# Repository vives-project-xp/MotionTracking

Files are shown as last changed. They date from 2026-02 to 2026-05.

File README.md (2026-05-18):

# Motion Tracking


> Een podium-tracking systeem die licht/visuals aanstuurt door middel van bewegingen van de artiest op het podium

## Opdracht

Het doel van dit project is het ontwikkelen van een **Podium-Tracking** systeem. Dit systeem is bedoeld om bewegingen van artiesten op te detecteren en deze accuraat te volgen. De data die hieruit voortvloeit wordt gebruikt om Licht/Visuals dynamisch te laten veranderen

## Inhoud

### Software

De broncode voor de tracking algoritmes en aansturing is te vinden in de [Software](Software/README.md) map. We maken gebruik van Python, OpenCV, YOLO,... voor de beeldverwerking en data-analyse.

### Documentatie

De algemene documentatie voor het project is te vinden in de [Documentatie](Documentatie/README.md) map. Hierin vind je technische specificaties, flowcharts en uitleg over de werking van het tracking algoritme.

### Research

Alle onderzoeken voor het project kan men terug vinden in de [Research](Research/README.md) map. Hierin vind je gevonden informatie, ruwe datasheets,...

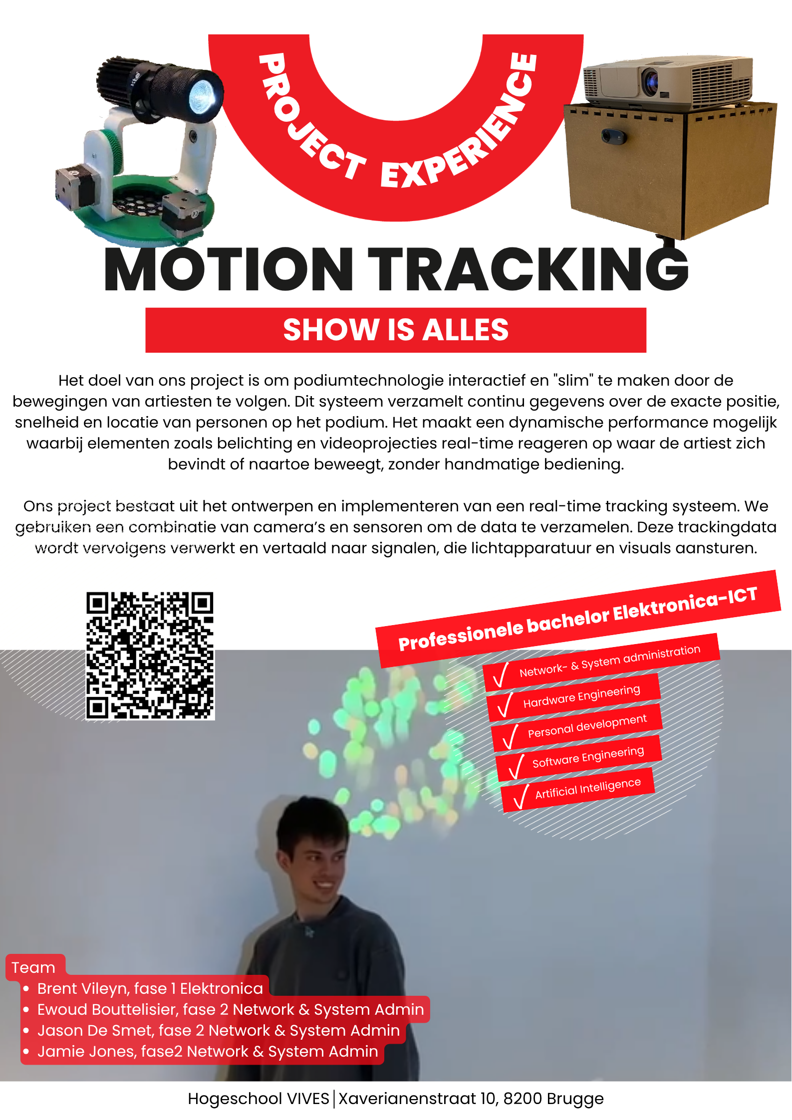
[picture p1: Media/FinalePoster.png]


### Installatie Motion Tracking met projector
#### Benodigdheden:
- Projector of groot scherm
- Raspberry Pi 5 + hailo ai kit
- USB Camera -> verbonden met raspberry
- Radxa Rock 5B of sterker apparaat   -> verbonden met projector
- Virtuele Machine op server of iets waar je website op kan hosten

#### Stappen:

1. **Clone** de github-repo op de Raspberry Pi 5, Rock en VM.

2. Lokaliseer de juiste **files** per **apparaat**: map Visual_output > Radxa Rock | map Hailo_tracking > Raspberry Pi 5 Hailo Kit | map Vm > Virtuele Machine op server

3. Sluit de **camera** aan op de Raspberry Pi 5 en de projector op de Radxa Rock

4. Zorg ervoor dat de Projector en camera steeds **goed gepositioneerd** blijven (dit kan met een statief + plaat).

5. Start het script **hailo_apps/hailo_app_python/start_tracking** op de Raspberry Pi en ook het script **visual_output/main.py** starten op de Rock.

6. Laat de camera de **fudicials** tracken, als de fudicials dan verdwijnen zou de **tracking** moeten **opgestart** zijn.

7. Surf naar het **IP-adres** van uw **VM** op poort 80:

```bash
[IP-Adres]:80
```

### Gebruik
1. **Start** alles **op** (zie installatie).

2. Ga **voor** de **camera** staan/bewegen om **effecten** te zien op de projector.

3. Pas **achtergronden** en **effecten** aan op de website om mooie **visuals** te krijgen.

### Installatie Motion Tracking met Moving Spot
#### Benodigdheden:
- 2X ESP32-C3-DevKitC-02
- Radar Sensor (mmWave-sensor) (Ai-Thinker Rd-03D 24GHz Radar Sensor Module)
- Arduino Uno
- QShield Servo Driver Board
- Servo Motoren (Nema 17)
- Spotlight Lamp (Eurolite LED PST-12W 6000K Spot)

#### Stappen voor installatie van Radar

 1. Lokaliseer de juiste **files** door te Navigeren naar : Software > Radar > Radar_code > Radar_code.ino .
 2. Verbind de Esp en de Radar met elkaar via een usb-a kabel.
 3. Upload de Radar_code.ino naar de esp.
 4. Hang de radar op de positie waar de personen wilt tracken.
 5. Verbind de radar via deze wijze :
    | Radar | ESP32          |
    |-------|----------------|
    | RX    | TX (Pin 18)    |
    | TX    | RX (Pin 19)    |
    | 5V    | 5V             |
    | GND   | GND            |

 #### Stappen voor MQTT Receiver Esp

 1. Lokaliseer de juiste **files** door te navigeren naar : Software > Radar > tweed_esp > mqtt_sender > mqtt_sender.ino 
 2. Connecteer je esp met je computer en upload de mqtt_sender.ino code naar je esp.
 3. Connecteer je esp met de arduino :

    | Pinout ESP | Pinout Arduino |
    |------------|----------------|
    | GND        | GND            |
    | TX (pin 21)| Pin 2          |
    | RX (pin 5) **optioneel**| Pin 3 **optioneel**|

## Team

| Team | Afstudeerrichting |
| --- | --- |
| [ Brent Vileyn](https://github.com/Brent69420809) | Elektronica |
| [ EwoudBoutje](https://github.com/EwoudBoutje) |  Network & System Admin  |
| [ Jason De Smet](https://github.com/JasonDeSmet2025) | Network & System Admin |
| [ Jamie Jones](https://github.com/JollyJones101) | Network & System Admin |

## Planning

### Sprint 1 (Week 1-4):
- [ ]  Alle componenten besteld
- [ ] Camera doen werken op Raspberry Pi + Scherm herkennen met testcode
- [ ] Radar Module onderzoeken + schema's maken
- [ ] Visuals onderzoeken + hoe uit pi krijgen

### Sprint 2 (Week 5-8)
- [ ] Eerst prototype afgewerkt
- [ ] Foto's & video's voor sociale media
- [ ] Visual dynamisch kunnen aanpassen aan artiest

### Sprint 3 (Week 9-15)
- [ ] volledig werkende visuals show
- [ ] eventuele uitbreidingen toepassen
- [ ] documentatie afgewerkt

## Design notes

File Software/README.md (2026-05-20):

# Software
> Hier vindt men alle software

## Bestandsstructuur

```text
Software/
└── Archief
    └── Oude mappen/bestanden
└── Arduino
    └── Files voor Arduino
└── Hailo_tracking
    └── basic_pipelines
    └── hailo_apps
└── Radar/
    └── Radar_Code/
        └── Radar_Code.ino
└── Visual_output
    └── demo_radar: files om radar te tonen op projector
    └── Markers: fiducials om projector uit te lezen
    └── Media: Foto's en video's voor op projector
    └── files om programma uit te voeren voor op de rock       
└── Vm
    └── files voor de website

```
---
## VM - Web control panel

De map `Vm` bevat de webinterface waarmee de visuals op afstand worden ingesteld. Deze software draait op de virtuele machine/server en stuurt configuratie door via MQTT naar het toestel dat de projectie uitvoert.

### Inhoud van de map

| Bestand/map | Functie |
|---|---|
| `webcontrol.py` | Hoofdversie van het Flask webpaneel. Dit script draait op poort `80`, laadt de styling uit `static/style.css` en publiceert instellingen naar MQTT. |
| `oldweb.py` | Oude versie van het webpaneel, bewaard als backup. |
| `static/style.css` | CSS-bestand voor de opmaak van de webinterface. Flask serveert dit bestand automatisch via de `static` map. |
| `Media/` | Wordt automatisch aangemaakt. Hierin komen geuploade afbeeldingen en videos terecht. |

### Werking

De VM draait een Flask-server. Via de website kan men:

- een achtergrondkleur kiezen;
- een afbeelding of video uploaden als achtergrond;
- media hernoemen of verwijderen;
- een effectmodus kiezen, zoals `MAGIC`, `FIRE`, `CYBER`, `GHOST` of `COWBOY`;
- parameters aanpassen zoals `offset` en `spawn`;
- de trackingbron en doelpersoon instellen.

Bij elke wijziging stuurt `webcontrol.py` de volledige configuratie als JSON naar het MQTT-topic:

```text
vj/config
```

De MQTT broker staat standaard ingesteld op:

```python
MQTT_BROKER = "127.0.0.1"
```

Dit betekent dat de MQTT broker op dezelfde VM moet draaien als het webpaneel.

De HTML van het controlepaneel staat nog in `webcontrol.py`, maar de visuele opmaak staat apart in `static/style.css`. Hierdoor kan de layout aangepast worden zonder de Flask-routes of MQTT-logica te wijzigen.

### Installatie op de VM

Installeer Python en de nodige packages:

```bash
pip install flask werkzeug paho-mqtt
```

Zorg ook dat er een MQTT broker draait, bijvoorbeeld Mosquitto:

```bash
sudo apt install mosquitto mosquitto-clients
sudo systemctl enable mosquitto
sudo systemctl start mosquitto
```

### Starten

Navigeer naar de map:

```bash
cd Software/Vm
```

Start daarna het webpaneel:

```bash
python3 webcontrol.py
```

De website is bereikbaar via:

```text
http://<VM-IP>:80
```

Let op: poort `80` vereist op Linux vaak administratorrechten. Gebruik in dat geval:

```bash
sudo python3 webcontrol.py
```

### Belangrijke endpoints

| Endpoint | Functie |
|---|---|
| `/` | Hoofdpagina van het controlepaneel. |
| `/update` | Past instellingen aan en publiceert deze via MQTT. |
| `/upload` | Uploadt afbeeldingen of videos naar de VM. |
| `/rename` | Hernoemt een mediabestand. |
| `/delete` | Verwijdert een mediabestand. |
| `/media/<filename>` | Maakt media beschikbaar voor de visual-output client. |
| `/get_config` | Geeft de huidige configuratie terug als JSON. |

---
## Visual_output - Projectie en effecten

De map `Visual_output` bevat de software die op het projectietoestel draait, bijvoorbeeld een Radxa Rock 5B. Deze software opent een fullscreen Pygame-venster op de projector en tekent effecten op basis van trackingdata en instellingen uit de VM.

### Inhoud van de map

| Bestand/map | Functie |
|---|---|
| `main.py` | Hoofdprogramma voor de live visual-output. |
| `effects_lib.py` | Bevat de effect-presets, particle-logica, aura-effecten en background manager. |
| `requirements.txt` | Python dependencies voor de visual-output software. |
| `Media/` | Lokale cache voor afbeeldingen en videos die als achtergrond gebruikt worden. |
| `Markers/` | ArUco/fiducial markers voor projectorkalibratie. |
| `demo_radar/` | Demo-opstelling voor radarvisualisatie. |
| `Back_up*.py`, `old-main.py`, `main3.py`, `main_website.py` | Oudere of experimentele versies van de visual-output. |
| `yolov8n.pt` | YOLO modelbestand voor detectie/testopstellingen. |

### Werking

`main.py` luistert via MQTT naar twee topics:

| Topic | Inhoud |
|---|---|
| `vj/hailo` | Trackingdata van personen en markers. |
| `vj/config` | Instellingen vanuit het VM-webpaneel. |

De trackingdata bevat onder andere personen, lichaamsposities en markerposities. De configuratie bepaalt de achtergrond, kleurmodus, particle-spawn en offset.

De belangrijkste stappen in het programma zijn:

1. Verbinden met de MQTT broker op de VM.
2. Fullscreen Pygame-venster openen op de projector.
3. Kalibratiemarkers tonen zolang het scherm nog niet gekalibreerd is.
4. Een perspectieftransformatie berekenen zodra de markers herkend worden.
5. Trackingpunten omzetten naar projectorcoordinaten.
6. Achtergrond tekenen.
7. Effecten, aura's en particles tekenen rond handen en hoofd.

### Configuratie

In `main.py` moet het IP-adres van de VM juist staan:

```python
VM_IP = "10.20.10.18"
```

Pas dit aan naar het IP-adres van de VM waarop `webcontrol.py` en de MQTT broker draaien.

### Installatie

Navigeer naar de map:

```bash
cd Software/Visual_output
```

Maak eventueel een virtuele omgeving aan:

```bash
python3 -m venv .venv
source .venv/bin/activate
```

Installeer daarna de dependencies:

```bash
pip install -r requirements.txt
```

De gebruikte packages zijn onder andere:

- `pygame`
- `opencv-python`
- `numpy`
- `requests`
- `paho-mqtt`

### Starten

Start de visual-output:

```bash
python3 main.py
```

Het programma opent in fullscreen. Gebruik deze toetsen tijdens het draaien:

| Toets | Functie |
|---|---|
| `ESC` | Programma afsluiten. |
| `C` | Kalibratie opnieuw uitvoeren. |
| `S` | Kalibratie overslaan en het volledige scherm gebruiken. |

### Achtergronden en media

Wanneer via de VM een afbeelding of video gekozen wordt, controleert `BackgroundManager` of het bestand lokaal bestaat in `Visual_output/Media`. Als het bestand ontbreekt, wordt het automatisch gedownload vanaf:

```text
http://<VM-IP>/media/<filename>
```

Zo hoeft media enkel via het webpaneel op de VM geupload te worden. De visual-output haalt de bestanden zelf op wanneer ze nodig zijn.

### Kalibratie

Bij het opstarten toont `main.py` vier markers op de hoeken van het projectiebeeld. De camera/trackingsoftware moet deze markers detecteren en via `vj/hailo` doorsturen. Zodra alle vier markers gekend zijn, berekent de visual-output een perspectieftransformatie zodat de trackingpunten correct op de projectie verschijnen.

Als de markers niet gebruikt worden of als er snel getest moet worden, kan met `S` een standaardmapping over het volledige scherm gebruikt worden.

---
## Ai-Thinker RD-03D Radar Software

### Hoe de software werkt

#### 1. Data Ontvangst
De sensor stuurt pakketjes van **30 bytes** via UART op **256000 baud**. De software controleert eerst de volledige header én footer om te bevestigen dat het om een geldig datapakket gaat:

| Positie | Waarde | Beschrijving |
|---|---|---|
| Byte 0  | `0xAA` | Header byte 1 |
| Byte 1  | `0xFF` | Header byte 2 |
| Byte 2  | `0x03` | Header byte 3 |
| Byte 3  | `0x00` | Header byte 4 |
| Byte 4-5 | variabel | X-coördinaat (little-endian) |
| Byte 6-7 | variabel | Y-coördinaat (little-endian) |
| Byte 8-9 | variabel | Snelheid |
| Byte 10-11 | variabel | Afstandsresolutie |
| Byte 12-27 | `0x00` | Target 2 & 3 (niet gebruikt) |
| Byte 28 | `0x55` | Footer byte 1 |
| Byte 29 | `0xCC` | Footer byte 2 |

De software valideert elk frame door de header (`0xAA 0xFF 0x03 0x00`) en footer (`0x55 0xCC`) te controleren. Frames die hier niet aan voldoen worden weggegooid.

---

#### 2. Coördinaat Decodering
De ruwe X- en Y-waardes worden samengesteld via little-endian optelling:
**X-coördinaat (links/rechts):**
De sensor gebruikt een gedeeld bereik rond 32768 (2¹⁵):
- Rechterkant (positief): `x_raw < 32768` → `x_mm = x_raw`
- Linkerkant (negatief): `x_raw >= 32768` → `x_mm = -(x_raw - 32768)`

**Y-coördinaat (afstand voorwaarts):**
$$y_{mm} = y_{raw} - 32768$$

---

#### 3. Wiskundige Berekening
De software rekent de X- en Y-coördinaten om naar poolcoördinaten:

**Afstand** via de stelling van Pythagoras:
$$\text{afstand} = \frac{\sqrt{x_{mm}^2 + y_{mm}^2}}{10} \text{ cm}$$

**Hoek** via atan2:
$$\text{hoek} = \arctan2(x_{mm},\ y_{mm}) \times \frac{180}{\pi} \text{ graden}$$

Waarbij $0°$ recht vooruit is voor de radar, positieve graden rechts en negatieve graden links.

---

#### 4. Filters
Om ongeldige frames te verwijderen:
1. **Frame lengte**: Exact 30 bytes.
2. **Header & footer**: Moeten exact overeenkomen.
3. **Y-waarde**: Moet groter zijn dan 0 (target moet voor de sensor staan).

---

#### 5. MQTT Verzending
Na een geldige meting wordt de data via WiFi gepubliceerd op het MQTT topic `vj/radar` als CSV-string:

---

#### Gebruik in de Arduino IDE

1. Stel jouw **WiFi credentials** in bovenaan de code.
2. Stel het correcte **MQTT broker IP-adres** in (`mqtt_server`).
3. Upload de code naar de ESP32.
4. Open de **Serial Monitor** (`Ctrl` + `Shift` + `L`) op **115200 baud**.
5. De ESP32 verbindt automatisch met WiFi en de MQTT broker.
6. Je ziet nu serial output zoals: *X,Y,Distance,Angle*

### Bij de Arduino Uno
Om de data te ontvangen van de MQTT broker bij de Arduino Uno (die wordt gebruikt om de motoren aan te sturen) gebruiken we een tweede ESP32 omdat deze wel met Wifi kan verbinden.
We subcriben op de top vj/radar.
Zo sturen we dan alle data die we binnenkrijgen van de topic over de TX-pin die verbonden is met pin 2 op de Arduino.
De code voor deze ESP32 kan je vinden in *Radar/tweede_esp*.

### Documentatie Arduino
De documentaie over de arduino kan men [hier](/Documentatie/README.md) vinden.

---

**Richting referentie:**
- Beweeg je naar **links**? → Hoek gaat naar **negatieve** graden.
- Beweeg je naar **rechts**? → Hoek gaat naar **positieve** graden.
- Recht voor de sensor = **0°**.

---

### Gebruikte Libraries

| Library | Functie | Installatie |
|---|---|---|
| `WiFi.h` | WiFi verbinding | Ingebouwd in ESP32 core |
| `PubSubClient.h` | MQTT communicatie | Via Arduino Library Manager |
| `Arduino.h` | Arduino basis | Ingebouwd |

--- 
### Gebruikte Driver
[Driver](https://www.silabs.com/documents/public/software/CP210x_Universal_Windows_Driver.zip)

# Werking van de Hailo AI

Voor dit project hebben we de officiële **Hailo voorbeelden** (examples) van GitHub gehaald. Omdat die code standaard alleen bedoeld is om dingen op een scherm te laten zien, hebben we de code zelf aangepast. Hierdoor kunnen we nu specifiek de houding (pose estimation) van mensen uitlezen en deze data doorsturen.

---

## 🚀 Hoe werkt de Hailo software in dit project?

De code van GitHub zorgt ervoor dat de camera en de Hailo AI-chip (de NPU) met elkaar praten. Dit gebeurt via een zogenaamde video-pipeline. 

Wij hebben ingegrepen op het moment dat er een video-beeld binnenkomt. De Hailo-software doet dan achter de schermen het zware werk:

1. **Scannen naar mensen:** De AI scant het beeld en zoekt naar objecten met het label `"person"`.
2. **Kader maken (Bounding Box):** Als de AI een persoon vindt, trekt hij er een onzichtbaar kader omheen. De software onthoudt de coördinaten van dit kader (waar begint en stopt de persoon in het beeld).
3. **Skeletpunten zoeken (Landmarks):** Binnen dat kader gaat de AI op zoek naar het 'skelet' van de persoon. 

---

## 🛠️ Wat hebben wij aangepast voor de Pose Estimation?

De standaard code van GitHub gooit alle data op één grote hoop. Wij hebben de code zo aangepast dat we heel specifiek drie belangrijke punten uit het skelet filteren:
* De **neus**
* De **linkerhand**
* De **rechterhand**

### De berekening simpel uitgelegd
De Hailo geeft de locatie van de hand of neus door *binnen het kader van de persoon zelf*, en dus niet binnen het hele videoscherm. 

Wij hebben code toegevoegd die dit omrekent. Onze aanpassing zorgt ervoor dat de software kijkt naar de grootte van het kader, berekent waar de hand zich bevindt op het totale scherm, en dit omzet naar een simpel getal tussen `0.0` (helemaal links/boven) en `1.0` (helemaal rechts/onder).

Hierdoor hebben we een super nauwkeurige meting van waar de neus en handen zijn, die we direct kunnen doorsturen via MQTT!

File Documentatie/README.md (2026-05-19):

# Documentatie
> Hier vindt men alle documentatie

# Pan and Tilt Joint
Voor dit project hebben wij een pan and tilt joint gebruikt dat alle richtingen in kan draaien. Hiervoor bestaat al een mooi bestaand project: https://www.thingiverse.com/thing:4316563
We kunnen hier vinden hoe wij het samenstellen: https://www.youtube.com/watch?v=uJO7mv4-0PY
Voor het grote rollement hebben wij dit ook uitgeprint en gesmeerd zodat het vlot draait.
Beide stepper motors, namelijk de NEMA-17, zijn verbonden met een QShield v5d en het shield is verbonden aan de Arduino. Het QShield heeft minimaal 12V nodig. We voeden het met een adapter van 12V en 2A, wat voldoende is voor onze stepper motors. Daarna hebben wij deze lamp gemonteerd op het statief: https://www.bax-shop.be/nl/pinspot/eurolite-led-pst-12w-6000k-spot-smalle-beam-pinspot. Dit moet niet deze lamp zijn, maar is onze voorkeur.

# Code Pan and Tilt Joint
De code werd geschreven in C++ in de Arduino IDE voor de Arduino Uno die wij in dit project gebruiken. De broncode is hier te vinden: https://github.com/vives-project-xp/MotionTracking/tree/main/Software/Arduino

# Code Uitleg
De code bestuurt twee stepper motors via een niet-blokkerende scheduler:
Y-as (tilt): Bij het opstarten wordt de Y-as eerst gehomed. De motor beweegt richting de eindschakelaar (NC-bedrading), raakt deze aan, en rijdt dan een vaste afstand terug zodat de carriage vrij staat. Daarna wordt de positie op nul gezet. Tijdens normaal gebruik wordt de tilt-positie berekend op basis van de ontvangen afstandswaarde (0–500 cm), die lineair wordt omgezet naar een stappenpositie tussen Y_MIN_STEPS (600) en Y_MAX_STEPS (2200).
Z-as (pan): De motor volgt een doelhoek die rechtstreeks uit het datapakket wordt gehaald. De hoek wordt begrensd tussen −90° en +90°.
Beide assen werken met een interval-gebaseerde scheduler in loop(): elke as krijgt per iteratie slechts een klein aantal stappen toegewezen (Y_STEPS_PER_TICK, Z_STEPS_PER_TICK), zodat de seriële communicatie nooit geblokkeerd wordt.
Datapakket formaat: De ESP stuurt kommagescheiden pakketten via software-UART:
x,y,afstand,hoek
De code leest veld 2 (afstand) en veld 3 (hoek) uit elk pakket en past de doelposities van beide assen aan.
Veiligheid: Software-limieten voorkomen dat de motoren buiten hun fysieke bereik rijden. De eindschakelaar wordt ook tijdens normaal gebruik live uitgelezen en herstart de Y-as positie als deze onverwacht geactiveerd wordt.
# Radar Code Documentatie

## Overzicht
Deze code leest de data van een **Ai-Thinker RD-03D** mmWave radar sensor via UART, verwerkt de ruwe frames naar bruikbare coördinaten en stuurt deze via **MQTT over WiFi** door naar de rest van het systeem.

---

## Benodigde Libraries

| Library | Functie | Installatie |
|---|---|---|
| `WiFi.h` | WiFi verbinding | Ingebouwd in ESP32 core |
| `PubSubClient.h` | MQTT communicatie | Via Arduino Library Manager |
| `secrets.h` | WiFi & MQTT credentials | Zelf aanmaken (zie hieronder) |

---
## Gebruikte Artikels

[**Klik Hier**](https://www.electroniclinic.com/rd-03d-mmwave-radar-multi-human-tracking-with-distance-speed-positioning/)

---
## Gebruikte driver 
[**Driver**](https://www.silabs.com/documents/public/software/CP210x_Universal_Windows_Driver.zip)

## Configuratie

### secrets.h
Maak een bestand `secrets.h` aan in dezelfde map als de `.ino` file met de volgende inhoud:

```cpp
#ifndef SECRETS_H
#define SECRETS_H

#define SECRET_SSID "JOUW_WIFI_NAAM"
#define SECRET_PASS "JOUW_WIFI_PASWOORD"
#define SECRET_MQTT_SERVER "JOUW_IP_MQTT_SERVER"

#endif
```

### Pin configuratie
| Definitie | Pin | Beschrijving |
|---|-----|---|
| `RX_PIN` | 19 | UART ontvangst van radar TX |
| `TX_PIN` | 18 | UART verzending naar radar RX |
| `BAUD_RATE` | 256000 | UART snelheid |

---

## Hoe de code werkt

### 1. Opstarten (`setup`)
- Start de seriële monitor op 115200 baud voor debug output
- Start UART communicatie met de radar op 256000 baud
- Stuurt het `Single_Target_Detection_CMD` commando naar de radar om single-target modus te activeren
- Verbindt met WiFi via `setup_wifi()`
- Verbindt met de MQTT broker

### 2. Hoofdlus (`loop`)
- Controleert of de MQTT verbinding nog actief is, anders herverbindt via `reconnect()`
- Leest continu bytes binnen van de radar via UART
- Wanneer de footer bytes `0x55 0xCC` gedetecteerd worden, wordt `processRadarData()` aangeroepen

### 3. Frame validatie (`isValidFrame`)
Elk frame wordt gevalideerd op:
- Exacte lengte van 30 bytes
- Correcte header: `0xAA 0xFF 0x03 0x00`
- Correcte footer: `0x55 0xCC`

Ongeldige frames worden direct weggegooid.

### 4. Data verwerking (`processRadarData`)

**Ruwe bytes uitlezen:**
- x_raw = byte[4] + byte[5] * 256
- y_raw = byte[6] + byte[7] * 256

**X-coördinaat decodering:**
- x_raw < 32768  →  x_mm = x_raw          (rechterkant, positief)
- x_raw >= 32768 →  x_mm = -(x_raw - 32768)  (linkerkant, negatief)

**Y-coördinaat decodering:**
- y_mm = y_raw - 32768
- Frames waarbij `y_mm <= 0` worden geskipt (geen target voor de sensor).

**Berekeningen:**
$$\text{afstand} = \frac{\sqrt{x_{mm}^2 + y_{mm}^2}}{10} \text{ cm}$$

$$\text{hoek} = \arctan2(x_{mm},\ y_{mm}) \times \frac{180}{\pi} \text{ graden}$$
---

### 5. MQTT Verzending
De data wordt als CSV-string gepubliceerd op topic `vj/radar`:

x_mm,y_mm,afstand_cm,hoek_graden

Voorbeeld:

727,2034,214.7,19.7

---

## Richting referentie

| Positie | Hoek |
|---|---|
| Recht voor de sensor | 0° |
| Rechterkant | Positieve graden (+) |
| Linkerkant | Negatieve graden (-) |

---

## Serial Monitor output
Bij een geldige meting zie je:

Afstand: 214.7 cm  |  Hoek: 19.7 deg  |  Snelheid: 0 cm/s
MQTT verstuurd: 727,2034,214.7,19.7

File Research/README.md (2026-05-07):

# Research
> Hier vindt men alle research die we gedaan hebben

## Eventuele opstelling
- 1x Beamer om visuals te projecteren
- 1x Raspberry Pi 5 voor dherkenning en uitsturen van beeld
- Eigen gemaakte moving-head/spot (2x servomotoren, Spotlamp, drivers, ESP32(of andere)) die de artiest zal volgen
- 1x radar sensor om de artiest precieser te kunnen volgen

# Research - Radar Sensor

## Doel van het project
Het doel van het project is om één of meerdere artiesten te volgen met een licht.

---

## Sensorkeuze

### Waarom de RD-03D?
We hebben direct gekozen voor de Ai-Thinker RD-03D mmWave radar. Deze sensor had twee grote voordelen die voor ons project belangrijk waren:

- **Nauwkeurige tracking**: De sensor volgt een persoon heel precies.
- **Onderscheid tussen mens en object**: De sensor heeft een ingebouwd library dat het verschil kan zien tussen een mens en een gewoon object.

Een nadeel is dat de sensor heel gevoelig is. Hij pikt dus snel bewegingen op, wat goed is voor tracking maar ook betekent dat er veel ruismetingen kunnen binnenkomen.

---

## Bronnen

De belangrijkste bronnen die we gebruikt hebben:

- **Officiële datasheet** van Ai-Thinker: hierin vonden we het frame formaat, de standaard baudrate (256000 bps) en de elektrische specificaties deze kan je vinden onder de map Research > Datasheets > Ai-Thinker Rd-03D 24GHz Radar Sensor Module_Datasheet.pdf
- **Artikel van Electronic Clinic**: [Real-time Human Tracking Radar with mmWave Sensor and ESP32-S3 Touchscreen](https://www.electroniclinic.com/real-time-human-tracking-radar-with-mmwave-sensor-and-esp32-s3-touchscreen/)

Via het artikel hebben we een code gevonden die frames van de sensor stuurt, hoe de berekeningen voor de hoek werken en hoe we de correcte `x_mm` en `y_mm` waarden konden berekenen uit de ruwe bytes.

---

## Bevindingen

### Wat werkte goed
De tracking zelf werkt heel goed. De sensor detecteert een persoon snel als hij beweegt en volgt die vloeiend. De nauwkeurigheid is voldoende voor gebruik op een podium.

### Problemen
Het grootste probleem dat we tegenkwamen was dat veel van de binnengekomen frames incorrect waren. De sensor stuurt namelijk ook frames zonder nuttige data. Hiervoor hebben we een filter geschreven die elk frame valideert door de header (`0xAA 0xFF 0x03 0x00`) en footer (`0x55 0xCC`) te controleren, en frames met een ongeldige Y-waarde te negeren.

De decoding van de X-coördinaat was ook niet meteen duidelijk. Via trial and error met de ruwe data hebben we uiteindelijk de correcte formule gevonden:
- **Rechterkant** (positief): `x_mm = x_raw` wanneer `x_raw < 32768`
- **Linkerkant** (negatief): `x_mm = -(x_raw - 32768)` wanneer `x_raw >= 32768`

---

## Technische keuzes

| Keuze | Reden |
|---|---|
| **ESP32** | Heeft ingebouwde WiFi, nodig voor communicatie |
| **WiFi** | Meest praktisch voor draadloze communicatie op een podium |
| **MQTT** | Makkelijk protocol zodat alle componenten van het project met elkaar kunnen communiceren |

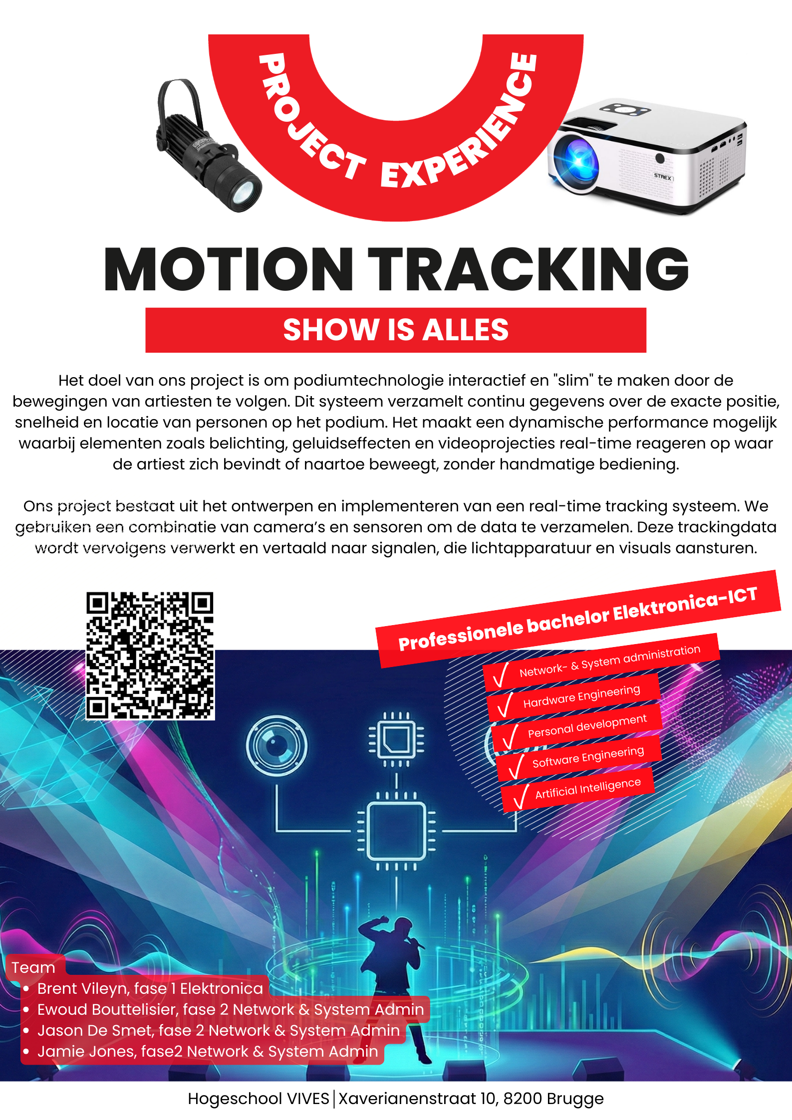
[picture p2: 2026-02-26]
Media/IntroductieposterPX9.png

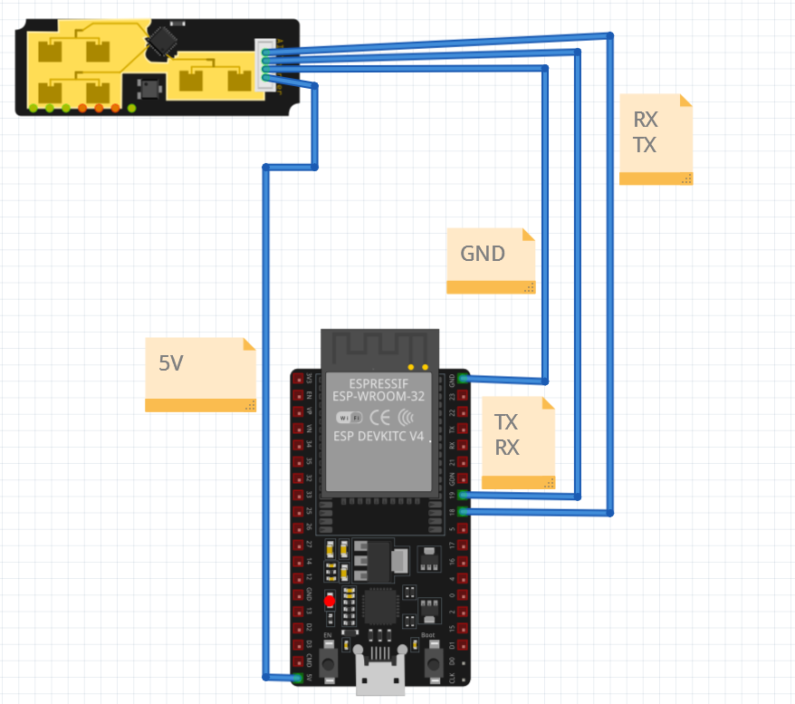
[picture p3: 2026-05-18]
Documentatie/schematics/Radar_schematic.png

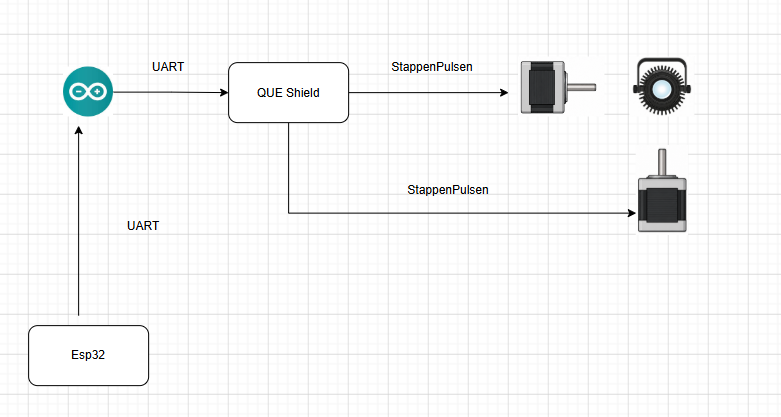
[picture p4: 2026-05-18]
Documentatie/schematics/Follow_Lamp_schematic.png

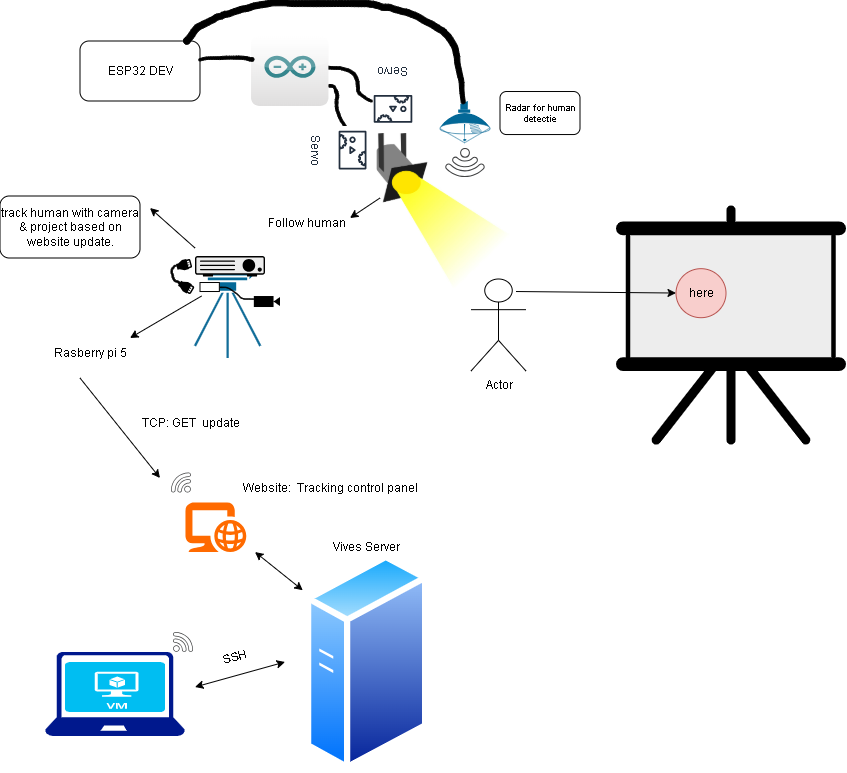
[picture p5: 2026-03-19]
Documentatie/schematics/Schematic.drawio.png

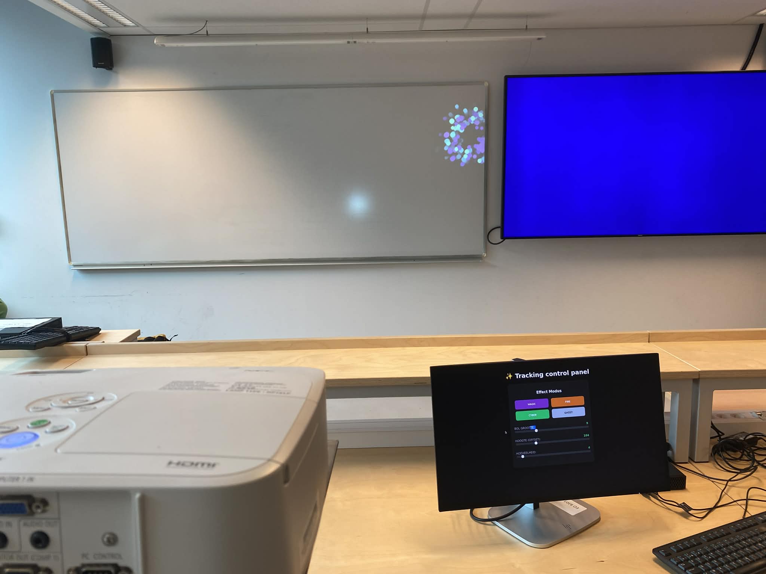
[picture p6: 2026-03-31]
Media/image_visuals.jpg

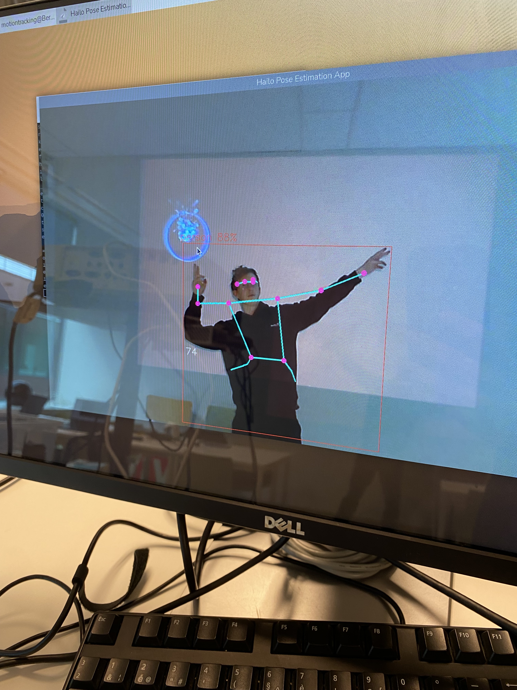
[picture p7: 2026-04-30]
Software/Visual_output/Media/Jamie.jpeg

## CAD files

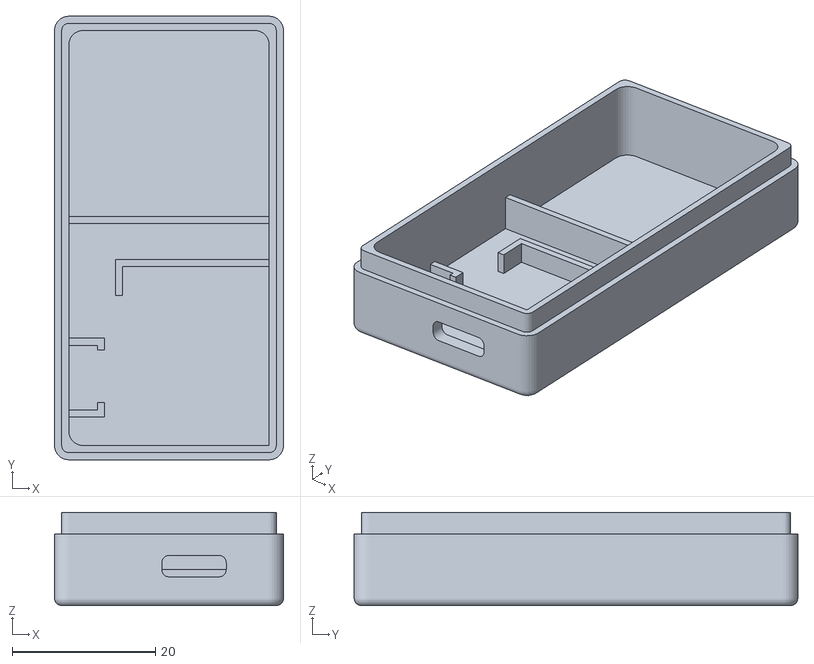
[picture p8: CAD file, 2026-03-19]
Archief/3Dfiles/Omhulsels/bottom_body_v2_ziSKXtXT1l.stl
32.0 x 62.0 x 13.0

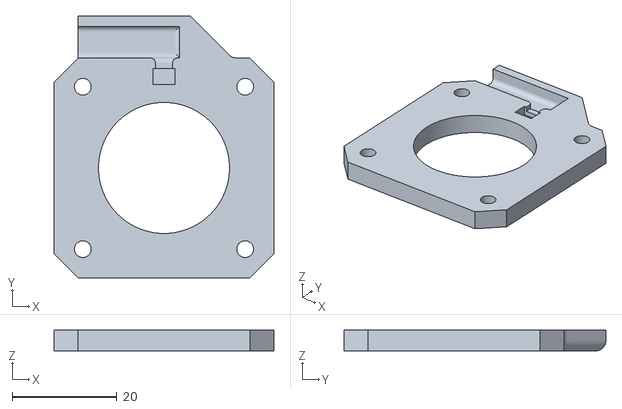
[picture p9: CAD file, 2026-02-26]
Archief/3Dfiles/Printed/Hall_Effect_Stepper_Mount.stl
42.0 x 50.0 x 4.00

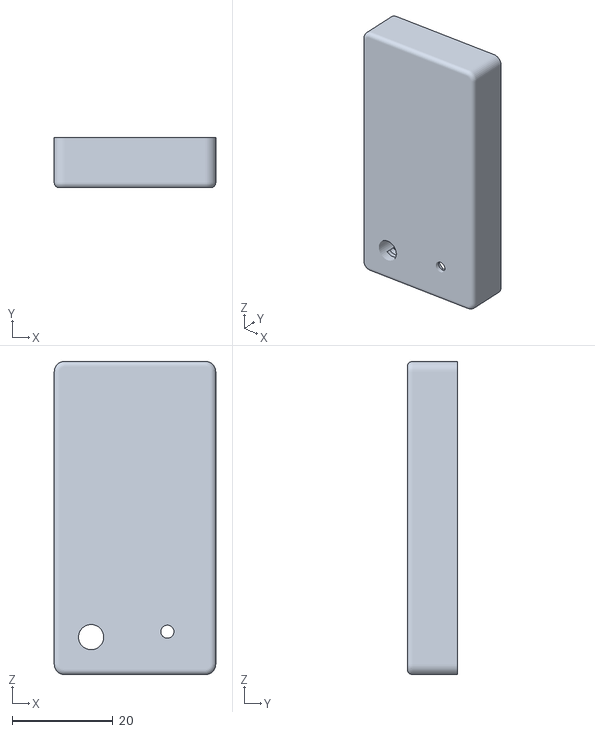
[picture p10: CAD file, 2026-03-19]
Archief/3Dfiles/Omhulsels/top_cover_v1_caKYhRjrv4.stl
32.0 x 10.0 x 62.0

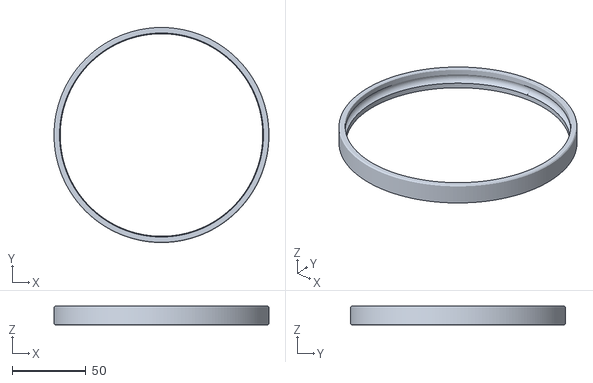
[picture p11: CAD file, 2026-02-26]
Archief/3Dfiles/Printed/127_x_146.05_x_12.7mm_Printable_Bearing_Part_1.stl
146.0 x 146.0 x 12.7

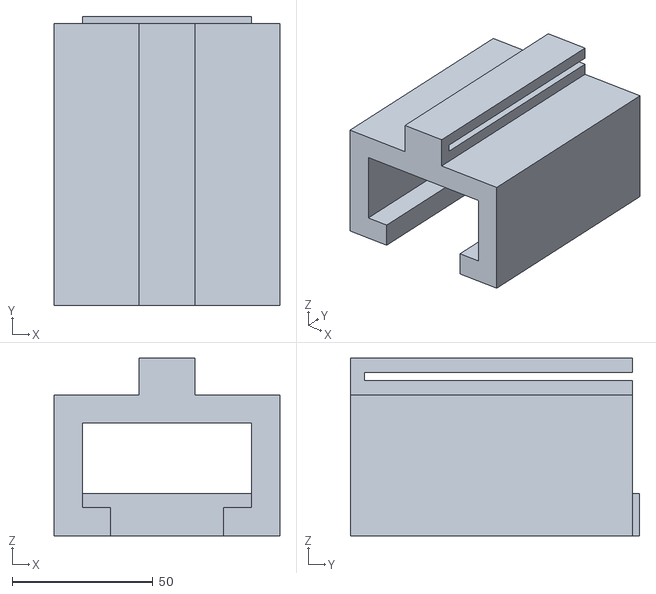
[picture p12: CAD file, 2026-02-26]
Archief/3Dfiles/Omhulsels/Railing.stl
80.0 x 102.5 x 63.0

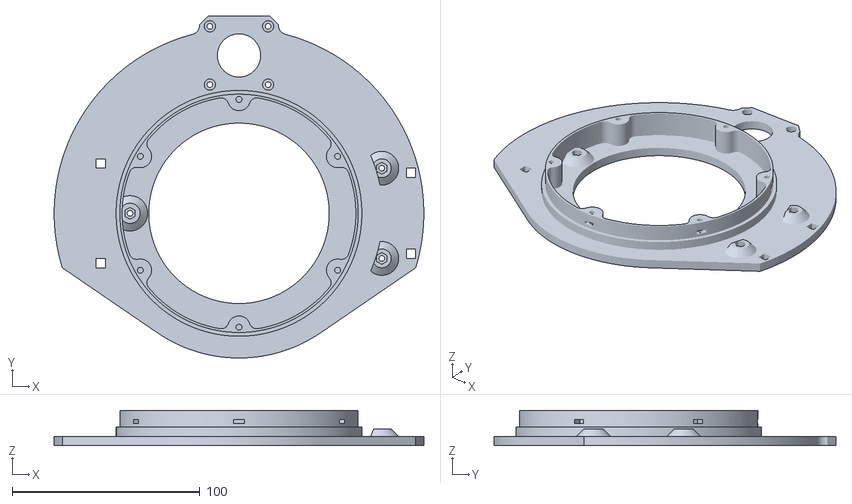
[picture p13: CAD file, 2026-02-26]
Archief/3Dfiles/Printed/Pan_Mount.stl
196.7 x 182.0 x 18.8

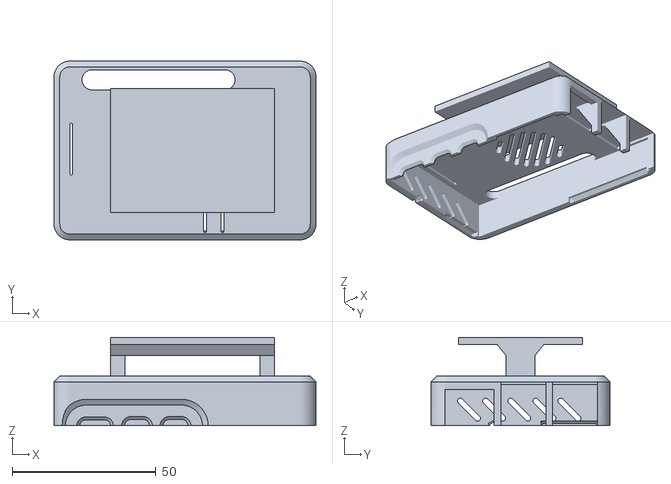
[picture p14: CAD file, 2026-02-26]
Archief/3Dfiles/Omhulsels/top_with_rail_attachedment.stl
91.2 x 62.2 x 30.8

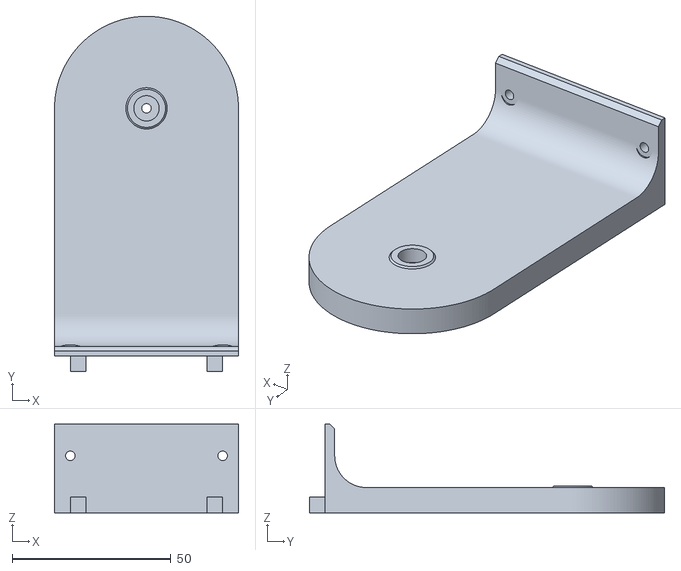
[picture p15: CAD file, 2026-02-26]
Archief/3Dfiles/Printed/Idle_Side_Support.stl
58.0 x 112.0 x 28.0

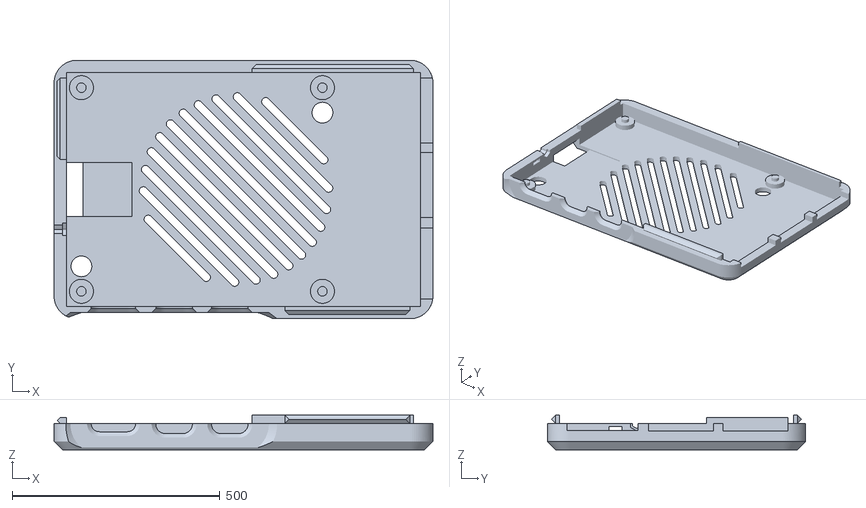
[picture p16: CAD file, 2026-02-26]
Archief/3Dfiles/Omhulsels/bottom_Raspberry.stl
912.0 x 622.0 x 83.2

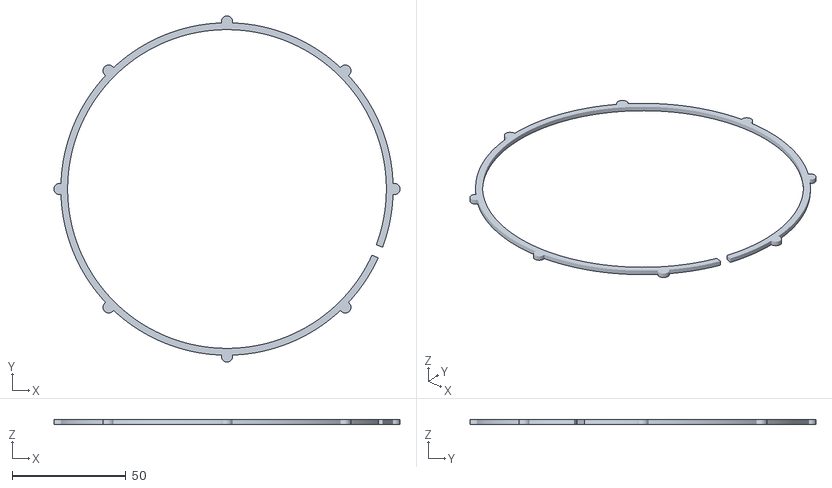
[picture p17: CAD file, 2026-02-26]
Archief/3Dfiles/Printed/Base_Mount_Bearing_Clip_Ring.stl
152.0 x 152.0 x 2.00

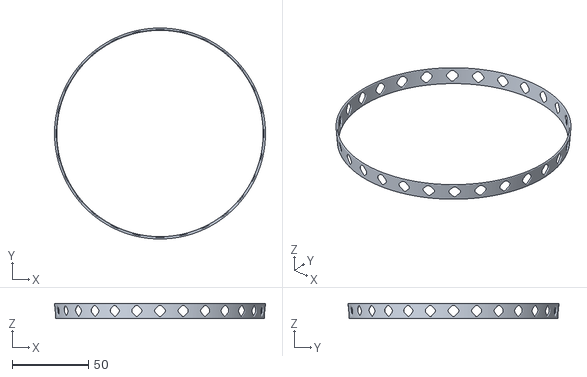
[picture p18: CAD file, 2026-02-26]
Archief/3Dfiles/Printed/127_x_146.05_x_12.7mm_Printable_Bearing_Cage_Part_3.stl
138.1 x 138.1 x 9.90

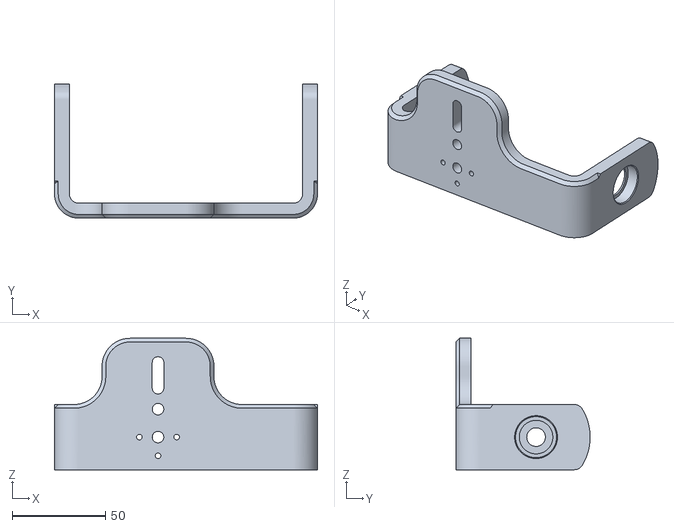
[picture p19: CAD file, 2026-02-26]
Archief/3Dfiles/Printed/Tilt_U-Mount.stl
141.0 x 72.0 x 70.5

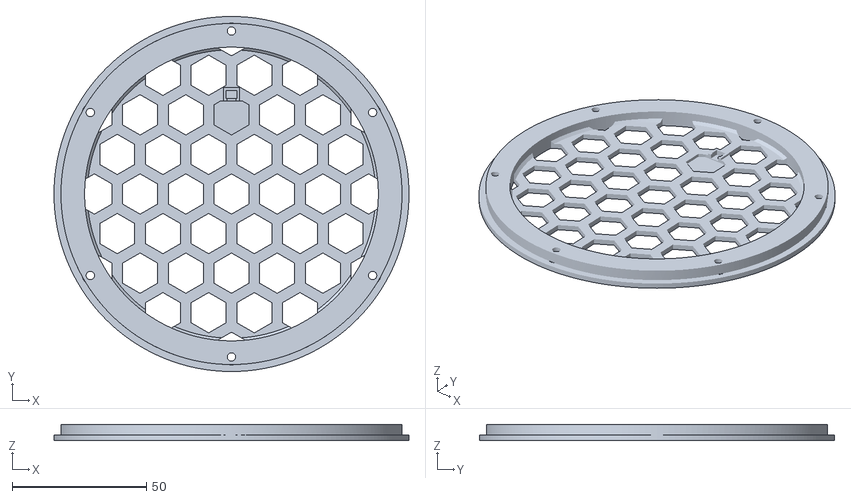
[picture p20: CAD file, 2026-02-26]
Archief/3Dfiles/Printed/Pan_Mount_Bearing_Clamp.stl
132.0 x 132.0 x 6.00

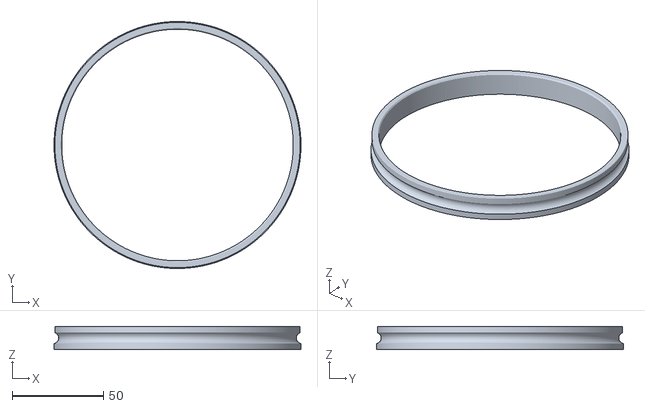
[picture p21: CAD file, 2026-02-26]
Archief/3Dfiles/Printed/127_x_146.05_x_12.7mm_Printable_Bearing_Part_2.stl
135.5 x 135.5 x 12.7

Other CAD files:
Archief/3Dfiles/Printed/Gear_Side_Support.stl
Archief/3Dfiles/Printed/Gear_Side_Bearing_Mount.stl
Archief/3Dfiles/Printed/Idle_Side_Bearing_Mount.stl
Archief/3Dfiles/Printed/Camera_Mounting_Bolt_Spacer.stl

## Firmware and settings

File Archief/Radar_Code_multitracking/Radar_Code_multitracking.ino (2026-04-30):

#include <WiFi.h>
#include <PubSubClient.h>
#include <RD03D.h>

// ============================================================
//  INSTELLINGEN
// ============================================================
const char* ssid        = "devbit";
const char* password    = "";
const char* mqtt_server = "10.20.10.18";

#define RADAR_RX 19
#define RADAR_TX 18


// ============================================================
//  PARAMETERS
// ============================================================
#define MAX_TRACKED       3
#define LOCK_TIMEOUT_MS   30000  // 30s → slot vrijgeven
#define FREEZE_TIMEOUT_MS 2000   // 2s niet gezien → 0,0 sturen
#define SMOOTHING         0.25f
#define ANGLE_MAX         80.0f
#define MATCH_RADIUS_MM   400
#define PUBLISH_INTERVAL  80
#define MIN_DISTANCE_MM   500    // Dichter dan 50cm = ongeldig (reflecties)
#define MAX_DISTANCE_MM   6000   // Verder dan 6m = ongeldig
#define MIN_Y_MM          200    // Y moet positief zijn (voor de sensor)
#define MIN_DIST_RES      50     // Minimum distanceRes voor betrouwbare meting
#define SMOOTHING         0.15f  // Rustiger dan 0.25
#define MATCH_RADIUS_MM   600    // Groter voor langere afstanden

// ============================================================
//  PER PERSOON
// ============================================================
struct TrackedPerson {
  bool          active;
  bool          locked;
  float         x;
  float         y;
  float         angle;
  float         distance;
  unsigned long lastSeen;
  unsigned long lockedAt;
};

TrackedPerson tracked[MAX_TRACKED];

// MQTT topics per persoon (zelfde als origineel)
const char* topicSimple[MAX_TRACKED] = {
  "vj/radar/persoon1",
  "vj/radar/persoon2",
  "vj/radar/persoon3"
};
const char* topicServo[MAX_TRACKED] = {
  "vj/radar/persoon1_servo",
  "vj/radar/persoon2_servo",
  "vj/radar/persoon3_servo"
};

// ============================================================
//  OBJECTEN
// ============================================================
WiFiClient   espClient;
PubSubClient client(espClient);
RD03D        radar(RADAR_RX, RADAR_TX);

// ============================================================
//  WIFI & MQTT
// ============================================================
void setup_wifi() {
  Serial.print("Verbinden met ");
  Serial.println(ssid);
  WiFi.begin(ssid, password);
  while (WiFi.status() != WL_CONNECTED) {
    delay(500);
    Serial.print(".");
  }
  Serial.println("\nWiFi verbonden!");
}

void reconnect() {
  while (!client.connected()) {
    Serial.print("Verbinden met MQTT... ");
    if (client.connect("ESP32_Radar")) {
      Serial.println("Verbonden!");
    } else {
      Serial.print("Mislukt, rc=");
      Serial.print(client.state());
      delay(2000);
    }
  }
}

// ============================================================
//  HULPFUNCTIES
// ============================================================
float calcAngle(float x, float y) {
  float angle = atan2(-x, y) * 180.0f / PI;
  if (angle >  ANGLE_MAX) return  ANGLE_MAX;
  if (angle < -ANGLE_MAX) return -ANGLE_MAX;
  return angle;
}

float pointDistance(float x1, float y1, float x2, float y2) {
  return sqrt(sq(x1 - x2) + sq(y1 - y2));
}

int findClosest(float x, float y) {
  int   bestIdx  = -1;
  float bestDist = MATCH_RADIUS_MM;
  for (int i = 0; i < MAX_TRACKED; i++) {
    if (!tracked[i].active || !tracked[i].locked) continue;
    float d = pointDistance(tracked[i].x, tracked[i].y, x, y);
    if (d < bestDist) {
      bestDist = d;
      bestIdx  = i;
    }
  }
  return bestIdx;
}

int findFreeSlot() {
  for (int i = 0; i < MAX_TRACKED; i++) {
    if (!tracked[i].active) return i;
  }
  return -1;
}

// ============================================================
//  LOCK BEHEER
// ============================================================
void checkLocks() {
  unsigned long now = millis();
  for (int i = 0; i < MAX_TRACKED; i++) {
    if (!tracked[i].active) continue;
    if (now - tracked[i].lockedAt > LOCK_TIMEOUT_MS) {
      Serial.printf("Persoon %d: 30s verlopen → slot vrijgegeven\n", i + 1);
      tracked[i].active = false;
      tracked[i].locked = false;
    }
  }
}

// ============================================================
//  TRACKING UPDATE
// ============================================================
void updateTracking(float rawX, float rawY, uint16_t distRes) {

  // --- FILTERS ---

  // 1. distanceRes te laag → onbetrouwbare meting
  if (distRes < MIN_DIST_RES) return;

  // 2. Y moet positief zijn (voor de sensor)
  if (rawY < MIN_Y_MM) return;

  // 3. Afstand berekenen en controleren
  float rawDistance = sqrt(sq(rawX) + sq(rawY));
  if (rawDistance < MIN_DISTANCE_MM || rawDistance > MAX_DISTANCE_MM) return;

  // 4. Hoek berekenen en clampen
  float rawAngle = atan2(-rawX, rawY) * 180.0f / PI;
  if (rawAngle > ANGLE_MAX || rawAngle < -ANGLE_MAX) return;

  // --- TRACKING ---
  unsigned long now = millis();
  int idx = findClosest(rawX, rawY);

  if (idx >= 0) {
    tracked[idx].x        = tracked[idx].x * (1.0f - SMOOTHING) + rawX * SMOOTHING;
    tracked[idx].y        = tracked[idx].y * (1.0f - SMOOTHING) + rawY * SMOOTHING;
    tracked[idx].angle    = calcAngle(tracked[idx].x, tracked[idx].y);
    tracked[idx].distance = sqrt(sq(tracked[idx].x) + sq(tracked[idx].y));
    tracked[idx].lastSeen = now;
  } else {
    idx = findFreeSlot();
    if (idx < 0) return;
    tracked[idx].active   = true;
    tracked[idx].locked   = true;
    tracked[idx].x        = rawX;
    tracked[idx].y        = rawY;
    tracked[idx].angle    = rawAngle;
    tracked[idx].distance = rawDistance;
    tracked[idx].lastSeen = now;
    tracked[idx].lockedAt = now;
    Serial.printf("Persoon %d gelockt! hoek: %.1f°  afstand: %.0fmm\n",
                  idx + 1, rawAngle, rawDistance);
  }
}

// ============================================================
//  SETUP
// ============================================================
void setup() {
  Serial.begin(115200);

  for (int i = 0; i < MAX_TRACKED; i++) {
    tracked[i].active = false;
    tracked[i].locked = false;
  }

  setup_wifi();
  client.setServer(mqtt_server, 1883);

  bool ok = radar.initialize(RD03D::MULTI_TARGET);
  Serial.println(ok ? "Radar gestart (multi-target)." : "Radar init MISLUKT!");
}

// ============================================================
//  LOOP
// ============================================================
// Vervang de loop() door dit:

void loop() {
  if (!client.connected()) reconnect();
  client.loop();

  radar.tasks();
  checkLocks();

  // Verzamel alle frames binnen 100ms window
  static float   sumX[RD03D::MAX_TARGETS]    = {0};
  static float   sumY[RD03D::MAX_TARGETS]    = {0};
  static uint32_t sumRes[RD03D::MAX_TARGETS] = {0};  // nieuw
  static int     count[RD03D::MAX_TARGETS]   = {0};

  for (int i = 0; i < RD03D::MAX_TARGETS; i++) {
    TargetData* tgt = radar.getTarget(i);
    if (tgt != nullptr && tgt->isValid()) {
      sumX[i]   += tgt->x;
      sumY[i]   += tgt->y;
      sumRes[i] += tgt->distanceRes;  // nieuw
      count[i]  += 1;
    }
  }

// Na 100ms window:
  for (int i = 0; i < RD03D::MAX_TARGETS; i++) {
    if (count[i] > 0) {
      float    avgX   = sumX[i]   / count[i];
      float    avgY   = sumY[i]   / count[i];
      uint16_t avgRes = sumRes[i] / count[i];  // nieuw
      updateTracking(avgX, avgY, avgRes);       // nieuw
    }
    sumX[i]   = 0;
    sumY[i]   = 0;
    sumRes[i] = 0;  // nieuw
    count[i]  = 0;
  }

    // MQTT publishen
    for (int i = 0; i < MAX_TRACKED; i++) {
      bool visible = tracked[i].active &&
                     tracked[i].locked &&
                     (millis() - tracked[i].lastSeen <= FREEZE_TIMEOUT_MS);

      if (visible) {
        String payloadSimple = String(tracked[i].angle, 1) + "," + String(tracked[i].distance, 1);
        String payloadServo  = String(tracked[i].x, 1) + "," + String(tracked[i].y, 1) + ",0," +
                               String(tracked[i].angle, 1) + "," + String(tracked[i].distance, 1);

        client.publish(topicSimple[i], payloadSimple.c_str());
        client.publish(topicServo[i],  payloadServo.c_str());

        Serial.printf("Persoon %d → %.1f°  %.0fmm\n", i + 1, tracked[i].angle, tracked[i].distance);
      } else {
        client.publish(topicSimple[i], "0,0");
        client.publish(topicServo[i],  "0,0,0,0,0");
      }
    }
  }

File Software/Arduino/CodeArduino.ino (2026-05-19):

#include <NeoSWSerial.h>

// NeoSWSerial: RX=2, TX=3 — do NOT use pin 2 or 3 for anything else
NeoSWSerial espSerial(2, 3);

// ----------------------------------------------------
// UART BUFFER
// ----------------------------------------------------
#define UART_BUFFER_SIZE 64
char uartBuffer[UART_BUFFER_SIZE];
int  uartIndex = 0;

// ----------------------------------------------------
// PINS  (Y_STEP was 3 — conflicted with espSerial RX!)
// ----------------------------------------------------
#define Y_STEP_PIN  3
#define Y_DIR_PIN   6

#define Z_STEP_PIN  4
#define Z_DIR_PIN   7

#define ENABLE_PIN  8
#define LIMIT_PIN   9      // NC wiring: LOW = free, HIGH = triggered

// ----------------------------------------------------
// STEPPER CONFIG
// ----------------------------------------------------
#define STEPS_PER_REV   14000
#define STEPS_PER_DEG   (STEPS_PER_REV / 360.0f)

#define PULSE_WIDTH_US  800

// How often (µs) each axis gets one step batch
#define INTERVAL_Y_US   1500
#define INTERVAL_Z_US   1500

// Y travel limits (steps)
#define Y_MAX_STEPS     2200
#define Y_MIN_STEPS     600

// Z angle limits
#define Z_MIN_ANGLE    -90.0f
#define Z_MAX_ANGLE     90.0f

// Dead-zones — stop hunting when close enough
#define Z_DEADZONE      2.0f
#define Y_DEADZONE      2

// Homing backoff distance
#define HOME_BACKOFF    700

// Steps moved per scheduler tick (non-blocking batches)
#define Y_STEPS_PER_TICK  5     // reduced — fewer steps per tick = more loop() turns
#define Z_STEPS_PER_TICK  1     // one degree per tick; increase if pan is too slow

// ----------------------------------------------------
// STATE
// ----------------------------------------------------
long  currentY    = 700;
long  targetY     = 700;

float currentAngle = 0.0f;
float targetAngle  = 0.0f;

unsigned long lastStepY = 0;
unsigned long lastStepZ = 0;

// ----------------------------------------------------
// FORWARD DECLARATIONS
// ----------------------------------------------------
void homeAxis();
void updateMotors();
void processPacket(char* line);
float extractField(char* s, int fieldIndex);
void stepY(int direction);
void stepZ(int direction);

// ====================================================
void setup() {
  Serial.begin(9600);
  espSerial.begin(9600);

  pinMode(Y_STEP_PIN, OUTPUT);
  pinMode(Y_DIR_PIN,  OUTPUT);
  pinMode(Z_STEP_PIN, OUTPUT);
  pinMode(Z_DIR_PIN,  OUTPUT);
  pinMode(ENABLE_PIN, OUTPUT);
  pinMode(LIMIT_PIN,  INPUT_PULLUP);

  digitalWrite(ENABLE_PIN, LOW);   // enable drivers

  delay(300);
  homeAxis();

  Serial.println("System ready.");
}

// ====================================================
void loop() {
  // --- Drain serial, build line ---
  while (espSerial.available()) {
    char c = espSerial.read();

    if (c == '\n' || c == '\r') {
      if (uartIndex > 0) {
        uartBuffer[uartIndex] = '\0';
        processPacket(uartBuffer);
        uartIndex = 0;
      }
    } else if (uartIndex < UART_BUFFER_SIZE - 1) {
      uartBuffer[uartIndex++] = c;
    }
  }

  updateMotors();
}

// ====================================================
// PACKET PARSING
// Format: x,y,distance,angle
// ====================================================
void processPacket(char* line) {
  float dist  = extractField(line, 2);   // 3rd field
  float angle = extractField(line, 3);   // 4th field

  // ---- Z axis (pan) ----
  if (angle > -9000.0f) {                // sentinel check
    angle = constrain(angle, Z_MIN_ANGLE, Z_MAX_ANGLE);
    targetAngle = angle;
  }

  // ---- Y axis (tilt) ----
  if (dist >= 0.0f) {
    dist = constrain(dist, 0.0f, 500.0f);
    targetY = (long)((1.0f - (dist / 500.0f)) * Y_MAX_STEPS);
    targetY = constrain(targetY, (long)Y_MIN_STEPS, (long)Y_MAX_STEPS);
  }
}

// ====================================================
// EXTRACT FIELD  (zero-indexed)
// Returns the numeric value of field[fieldIndex].
// Returns -9999 on failure so callers can detect "not found".
// ====================================================
float extractField(char* s, int fieldIndex) {
  int field = 0;
  int i     = 0;

  while (s[i] != '\0') {
    if (s[i] == ',') {
      field++;
      i++;
      continue;
    }

    if (field == fieldIndex) {
      // Make sure there's at least one digit/sign character
      if (s[i] == '-' || s[i] == '+' || (s[i] >= '0' && s[i] <= '9')) {
        return atof(&s[i]);
      } else {
        return -9999.0f;   // field exists but not numeric
      }
    }
    i++;
  }
  return -9999.0f;   // field not found
}

// ====================================================
// NON-BLOCKING MOTOR SCHEDULER
// Called every loop() iteration; does at most one small
// batch of steps per axis so serial never starves.
// ====================================================
void updateMotors() {
  unsigned long now = micros();

  // ---- Z axis (pan) ----
  float deltaZ = targetAngle - currentAngle;
  if (fabs(deltaZ) > Z_DEADZONE) {
    if (now - lastStepZ >= (unsigned long)INTERVAL_Z_US) {
      lastStepZ = now;
      int dir = (deltaZ > 0) ? 1 : -1;
      // Step multiple degrees if far away (faster slew), but cap to remaining
      int stepsNeeded = (int)(fabs(deltaZ) * STEPS_PER_DEG);
      int stepsThisTick = min(stepsNeeded, (int)(Z_STEPS_PER_TICK * STEPS_PER_DEG));

      digitalWrite(Z_DIR_PIN, dir > 0 ? HIGH : LOW);
      for (int i = 0; i < stepsThisTick; i++) {
        digitalWrite(Z_STEP_PIN, HIGH);
        delayMicroseconds(PULSE_WIDTH_US);
        digitalWrite(Z_STEP_PIN, LOW);
        delayMicroseconds(PULSE_WIDTH_US);   // equal off-time
      }
      // Update angle proportionally
      currentAngle += dir * (stepsThisTick / STEPS_PER_DEG);
    }
  }

  // ---- Y axis (tilt) ----
  long deltaY = targetY - currentY;
  if (abs(deltaY) > Y_DEADZONE) {
    if (now - lastStepY >= (unsigned long)INTERVAL_Y_US) {
      lastStepY = now;
      int dir = (deltaY > 0) ? 1 : -1;

      // Guard against limit switch during normal movement too
      if (dir < 0 && digitalRead(LIMIT_PIN) == HIGH) {
        // Limit hit unexpectedly — re-zero and stop
        currentY = 0;
        targetY  = 0;
        Serial.println("WARN: limit hit outside homing — re-zeroed.");
        return;
      }

      int stepsToMove = min((long)Y_STEPS_PER_TICK, abs(deltaY));

      digitalWrite(Y_DIR_PIN, dir > 0 ? HIGH : LOW);
      for (int i = 0; i < stepsToMove; i++) {
        // Hard software limits
        if (dir > 0 && currentY >= Y_MAX_STEPS) break;
        if (dir < 0 && currentY <= Y_MIN_STEPS) break;

        // Live limit-switch check every step when moving toward home
        if (dir < 0 && digitalRead(LIMIT_PIN) == HIGH) {
          currentY = 0;
          targetY  = 0;
          Serial.println("WARN: limit triggered mid-move.");
          break;
        }

        digitalWrite(Y_STEP_PIN, HIGH);
        delayMicroseconds(PULSE_WIDTH_US);
        digitalWrite(Y_STEP_PIN, LOW);
        delayMicroseconds(PULSE_WIDTH_US);
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

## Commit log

2026-02-12 Radar sensor schematic added
    [Radar_Sensor_Schematic.fzz]
2026-02-12 Picture of schematic added
2026-02-26 Stl files added
    [Radar_Sensor_Schematic.fzz, Railing_Omhulsels.stl, bottom_Raspberry.stl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]
2026-02-26 move files
    [127_x_146.05_x_12.7mm_Printable_Bearing_Cage_Part_3.stl, 127_x_146.05_x_12.7mm_Printable_Bearing_Part_1.stl, 127_x_146.05_x_12.7mm_Printable_Bearing_Part_2.stl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]
2026-02-26 3d folder deleted
    [Railing.stl, Railing_Omhulsels.stl]
2026-03-05 oudere code gearchiveerd
2026-03-05 Add calibration formula image for radar research
2026-03-19 documentatie radar geschreven en in readme van software de radar uitgelegt
2026-03-19 radar case added
    [bottom_body_v2_ziSKXtXT1l.stl, top_cover_v1_caKYhRjrv4.stl]
2026-03-19 fixed bottom position
    [bottom_body_v2_ziSKXtXT1l.stl]
2026-03-26 code for new esp linked to arduino
2026-04-02 update radar code and fixed library
    [Radar_Code.ino]
2026-04-29 Fixed bugs on radar
    [Radar_Code.ino, Radar_Code_multitracking.ino, mqtt_sender.ino]
2026-05-13 Fix typo in USB Camera connection description
2026-05-18 fritzing pi naar esp veranderd
    [Radar_Sensor_Schematic.fzz]
2026-05-18 Follow lamp schematic gemaakt
2026-05-18 Radar schematic added
    [Radar_Sensor_Schematic.fzz]
2026-05-18 Documentatie geupdate voor de nieuwe code
    [Radar_Sensor_Schematic.fzz]
2026-05-19 gebruikte driver van radar toegevoegd aan documentatie
